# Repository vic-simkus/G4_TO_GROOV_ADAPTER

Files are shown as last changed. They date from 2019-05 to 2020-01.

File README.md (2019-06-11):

# G4 TO GROOV ADAPTER
## Motivation
I found out, after purchasing a pile of gear, that the G4 output modules mounted in a G4PB24 would not work with a GRV-ODCSRC-24.  Reason being that the GRV-ODCSRC-24 is a "sourcing" module, while the G4PB24 expects a "sinking" module.  

While this could have been better documented by OPTO 22, it is what is it and I needed to be able to used the G4PB24 for my project.  Nothing else would do for various reasons.

Hence this project.  The project is an adapter board with a 50 pin ribbon connector on one end and a spring loaded terminal on the other end.  The design is super simple - it's 24 NPN transistors.  

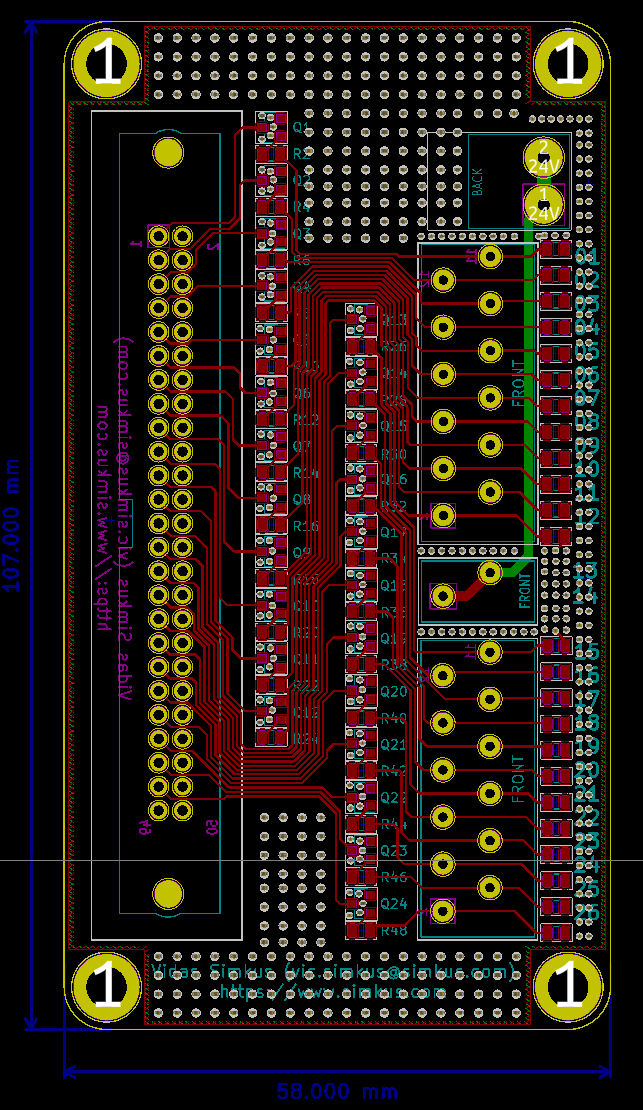
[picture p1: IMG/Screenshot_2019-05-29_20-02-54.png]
Board screen shot


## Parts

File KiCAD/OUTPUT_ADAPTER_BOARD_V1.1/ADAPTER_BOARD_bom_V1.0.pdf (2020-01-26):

ADAPTER_BOARD_bom_V1.0
Description | References | Value | Quantity
Connector, 02x25 | BOARD1 | | 1
Connector, 01x02 | PLC24 | | 1
Connector, 01x12 | PLC1-12 PLC13-14 | | 2
NPN transistor | Q1 Q2 Q3 Q4 Q5 Q6 Q7 Q8 Q9 Q10 Q11 Q12 Q13 Q14 Q15 Q16 Q17 Q18 Q19 Q20 Q21 Q22 Q23 Q24 | | 24
Resistor | R2 R4 R6 R8 R10 R12 R14 R16 R18 R20 R22 R24 R26 R28 R30 R32 R34 R36 R38 R40 R42 R44 R46 R48 | 10K | 24
Resistor | R1 R3 R5 R7 R9 R11 R13 R15 R17 R19 R21 R23 R25 R27 R29 R31 R33 R35 R37 R39 R41 R43 R45 R47 | 5K6 | 24
Connector, 01x02 | VDC24 | | 1

ADAPTER_BOARD_bom_V1.0
MFG | MFGPN | DKPN
AMPHENOL ICC (FCI) | 71918-150LF | 609-1759-ND
PHOENIX CONTACT | 1990009 | 277-1794-ND
PHOENIX CONTACT | 1990106 | 277-1804-ND
Diodes Incorporated | MMBTA42-7-F | MMBTA42-FDICT-ND
TE Connectivity Passive Product | CRGCQ0805F10K | A129761CT-ND
Panasonic Electronic Components | ERJ-P06J562V | P5.6KADCT-ND
PHOENIX CONTACT | 1990009 | 277-1794-ND

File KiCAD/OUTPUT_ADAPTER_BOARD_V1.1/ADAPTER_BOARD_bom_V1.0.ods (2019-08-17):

Description | References | Value | Quantity | MFG | MFGPN | DKPN
Connector, 02x25 | BOARD1 |  | 1 | AMPHENOL ICC (FCI) | 71918-150LF | 609-1759-ND
Connector, 01x02 | PLC24 |  | 1 | PHOENIX CONTACT | 1990009 | 277-1794-ND
Connector, 01x12 | PLC1-12 PLC13-14 |  | 2 | PHOENIX CONTACT | 1990106 | 277-1804-ND
NPN transistor | Q1 Q2 Q3 Q4 Q5 Q6 Q7 Q8 Q9 Q10 Q11 Q12 Q13 Q14 Q15 Q16 Q17 Q18 Q19 Q20 Q21 Q22 Q23 Q24 |  | 24 | Diodes Incorporated | MMBTA42-7-F | MMBTA42-FDICT-ND
Resistor | R2 R4 R6 R8 R10 R12 R14 R16 R18 R20 R22 R24 R26 R28 R30 R32 R34 R36 R38 R40 R42 R44 R46 R48 | 10K | 24 | TE Connectivity Passive Product | CRGCQ0805F10K | A129761CT-ND
Resistor | R1 R3 R5 R7 R9 R11 R13 R15 R17 R19 R21 R23 R25 R27 R29 R31 R33 R35 R37 R39 R41 R43 R45 R47 | 5K6 | 24 | Panasonic Electronic Components | ERJ-P06J562V | P5.6KADCT-ND
Connector, 01x02 | VDC24 |  | 1 | PHOENIX CONTACT | 1990009 | 277-1794-ND

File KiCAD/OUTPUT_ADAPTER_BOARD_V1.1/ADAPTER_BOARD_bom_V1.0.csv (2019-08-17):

Component | Description | Part | References | Value | Footprint | Quantity Per PCB | Datasheet | MFG | MFGPN | DKPN | TCR | TOL | PD
1 | Generic connector, double row, 02x25, odd/even pin numbering scheme (row 1 odd numbers, row 2 even numbers), script generated (kicad-library-utils/schlib/autogen/connector/) | Conn_02x25_Odd_Even | BOARD1 | Conn_02x25_Odd_Even | FCI_50PIN | 1 | ~ | AMPHENOL ICC (FCI) | 71918-150LF | 609-1759-ND
2 | Generic connector, single row, 01x02, script generated (kicad-library-utils/schlib/autogen/connector/) | Conn_01x02 | PLC24 | Conn_01x02 | 2_POS_SPRING_TERM | 1 | ~ | PHOENIX CONTACT | 1990009 | 277-1794-ND
3 | Generic connector, single row, 01x12, script generated (kicad-library-utils/schlib/autogen/connector/) | Conn_01x12 | PLC1-12 PLC13-14 | Conn_01x12 | 12_POS_SPRING_TERM | 2 | ~ | PHOENIX CONTACT | 1990106 | 277-1804-ND
4 | NPN transistor, base/emitter/collector | Q_NPN_BEC | Q1 Q2 Q3 Q4 Q5 Q6 Q7 Q8 Q9 Q10 Q11 Q12 Q13 Q14 Q15 Q16 Q17 Q18 Q19 Q20 Q21 Q22 Q23 Q24 | Q_NPN_CBE | SOT-23 | 24 | ~ | Diodes Incorporated | MMBTA42-7-F | MMBTA42-FDICT-ND
5 | Resistor | R | R2 R4 R6 R8 R10 R12 R14 R16 R18 R20 R22 R24 R26 R28 R30 R32 R34 R36 R38 R40 R42 R44 R46 R48 | 10K | R_0805_2012Metric | 24 | ~ | TE Connectivity Passive Product | CRGCQ0805F10K | A129761CT-ND | 100 | 1%
6 | Resistor | R | R1 R3 R5 R7 R9 R11 R13 R15 R17 R19 R21 R23 R25 R27 R29 R31 R33 R35 R37 R39 R41 R43 R45 R47 | 5K6 | R_0805_2012Metric | 24 | ~ | Panasonic Electronic Components | ERJ-P06J562V | P5.6KADCT-ND | 200 | 5% | 0.5W
7 | Generic connector, single row, 01x02, script generated (kicad-library-utils/schlib/autogen/connector/) | Conn_01x02 | VDC24 | Conn_01x02 | 2_POS_SCREW_TERM | 1 | ~ | PHOENIX CONTACT | 1990009 | 277-1794-ND
Component Groups: | 7
Component Count: | 77
Fitted Components: | 77
Number of PCBs: | 1
Total components: | 77
Schematic Version: | V1.0
Schematic Date: | 2019-05-24
BoM Date: | Fri 16 Aug 2019 07:38:34 PM CDT
Schematic Source: | /opt/dev/git_work/G4_TO_GROOV_ADAPTER/KiCAD/OUTPUT_ADAPTER_BOARD_V1.1/ADAPTER_BOARD.sch
KiCad Version: | Eeschema 5.0.2-bee76a0~70~ubuntu18.04.1

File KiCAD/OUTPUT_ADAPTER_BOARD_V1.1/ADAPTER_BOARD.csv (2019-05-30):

Id | Designator | Package | Quantity | Designation | Supplier and ref
1 | BOARD1 | FCI_50PIN | 1 | Conn_02x25_Odd_Even
2 | PLC1-12,PLC13-14 | 12_POS_SPRING_TERM | 2 | Conn_01x12
3 | PLC24 | 2_POS_SPRING_TERM | 1 | Conn_01x02
4 | R18,R2,R4,R6,R8,R10,R12,R14,R16,R20,R22,R24,R26,R28,R30,R32,R34,R36,R38,R40,R42,R44,R46,R48 | R_0805_2012Metric | 24 | 2K2
5 | Q5,Q1,Q2,Q3,Q4,Q6,Q7,Q8,Q9,Q10,Q11,Q12,Q13,Q14,Q15,Q16,Q17,Q18,Q19,Q20,Q21,Q22,Q23,Q24 | SOT-23 | 24 | Q_NPN_CBE
6 | VDC24 | 2_POS_SCREW_TERM | 1 | Conn_01x02
7 | REF**,REF**,REF**,REF** | MountingHole_4.3mm_M4_ISO14580_Pad | 4 | MountingHole_4.3mm_M4_ISO14580_Pad
8 | R1,R3,R5,R7,R9,R11,R13,R15,R17,R19,R21,R23,R25,R27,R29,R31,R33,R35,R37,R39,R41,R43,R45,R47 | R_0805_2012Metric | 24 | 10K

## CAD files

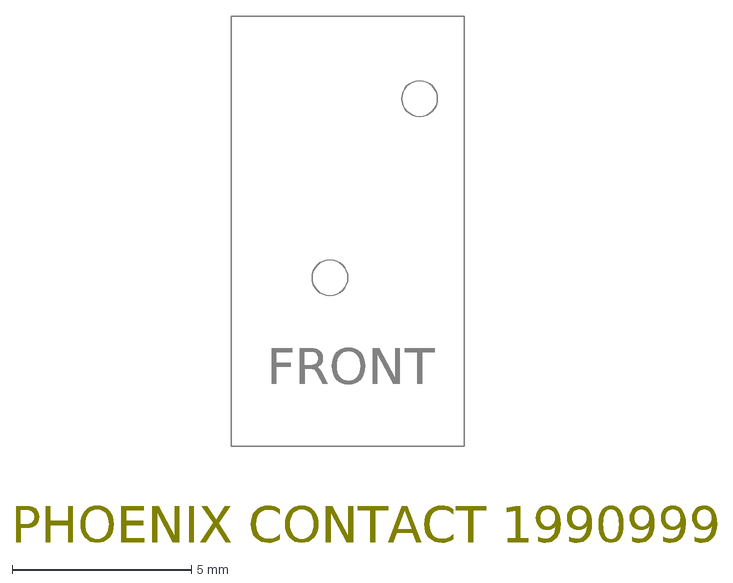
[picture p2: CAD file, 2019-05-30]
CAD/2POS_PCB_TERM_SPRING.dxf
FRONT
PHOENIX CONTACT 1990999

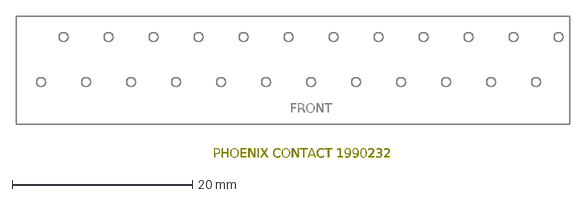
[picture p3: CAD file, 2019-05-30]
CAD/24POS_PCB_TERM.dxf
FRONT
PHOENIX CONTACT 1990232

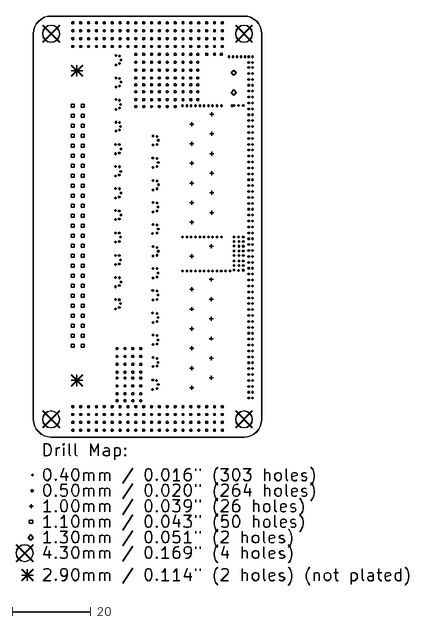
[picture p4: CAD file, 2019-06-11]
KiCAD/OUTPUT_ADAPTER_BOARD_V1.1/DXF/ADAPTER_BOARD-drl_map.dxf
99.7 x 144.6

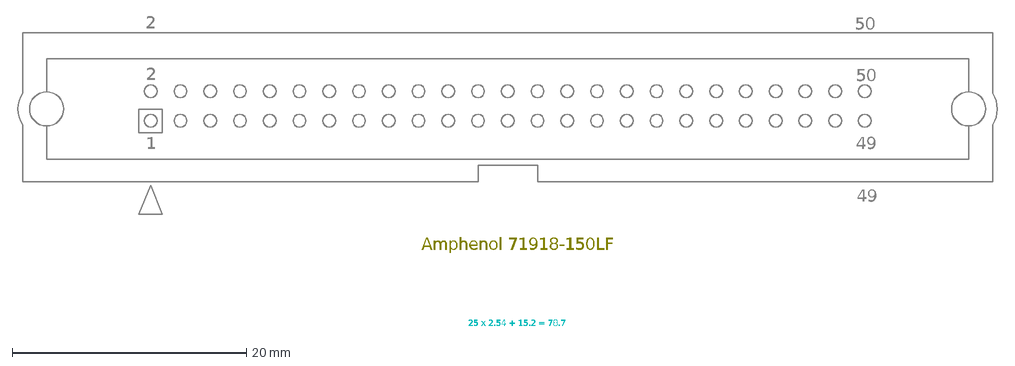
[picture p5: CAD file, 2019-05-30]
CAD/CONN-50PIN.dxf
1
49
50
2
25 x 2.54 + 15.2 = 78.7
Amphenol 71918-150LF

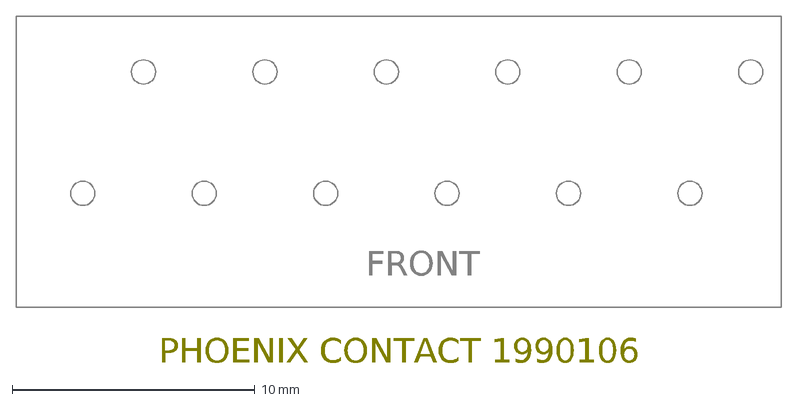
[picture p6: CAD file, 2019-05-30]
CAD/12POS_PCB_TERM_SPRING.dxf
FRONT
PHOENIX CONTACT 1990106

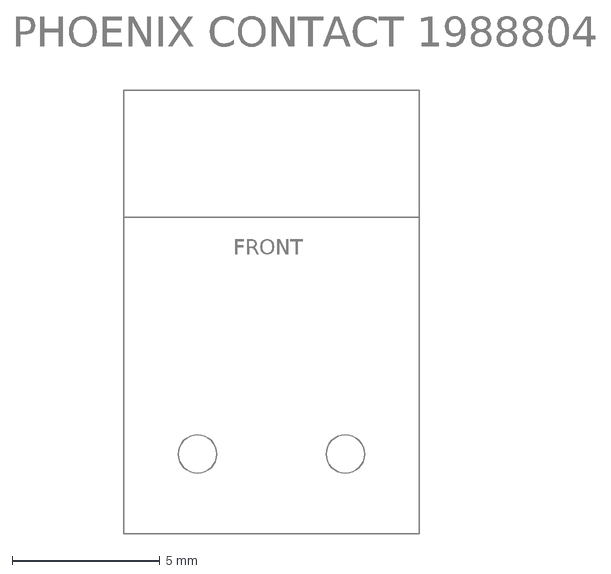
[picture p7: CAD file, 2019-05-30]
CAD/2POS_PCB_TERM.dxf
PHOENIX CONTACT 1988804
FRONT

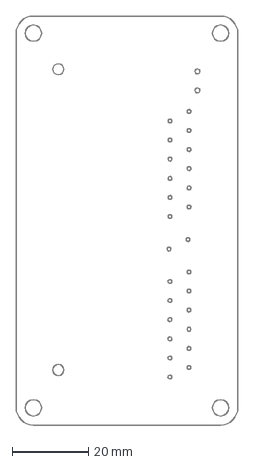
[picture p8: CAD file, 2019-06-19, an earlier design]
KiCAD/OUTPUT_ADAPTER_BOARD/DXF/ADAPTER_BOARD-layout.dxf
58.0 x 107.0 mm

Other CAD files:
KiCAD/OUTPUT_ADAPTER_BOARD_V1.1/DXF/ADAPTER_BOARD.dxf

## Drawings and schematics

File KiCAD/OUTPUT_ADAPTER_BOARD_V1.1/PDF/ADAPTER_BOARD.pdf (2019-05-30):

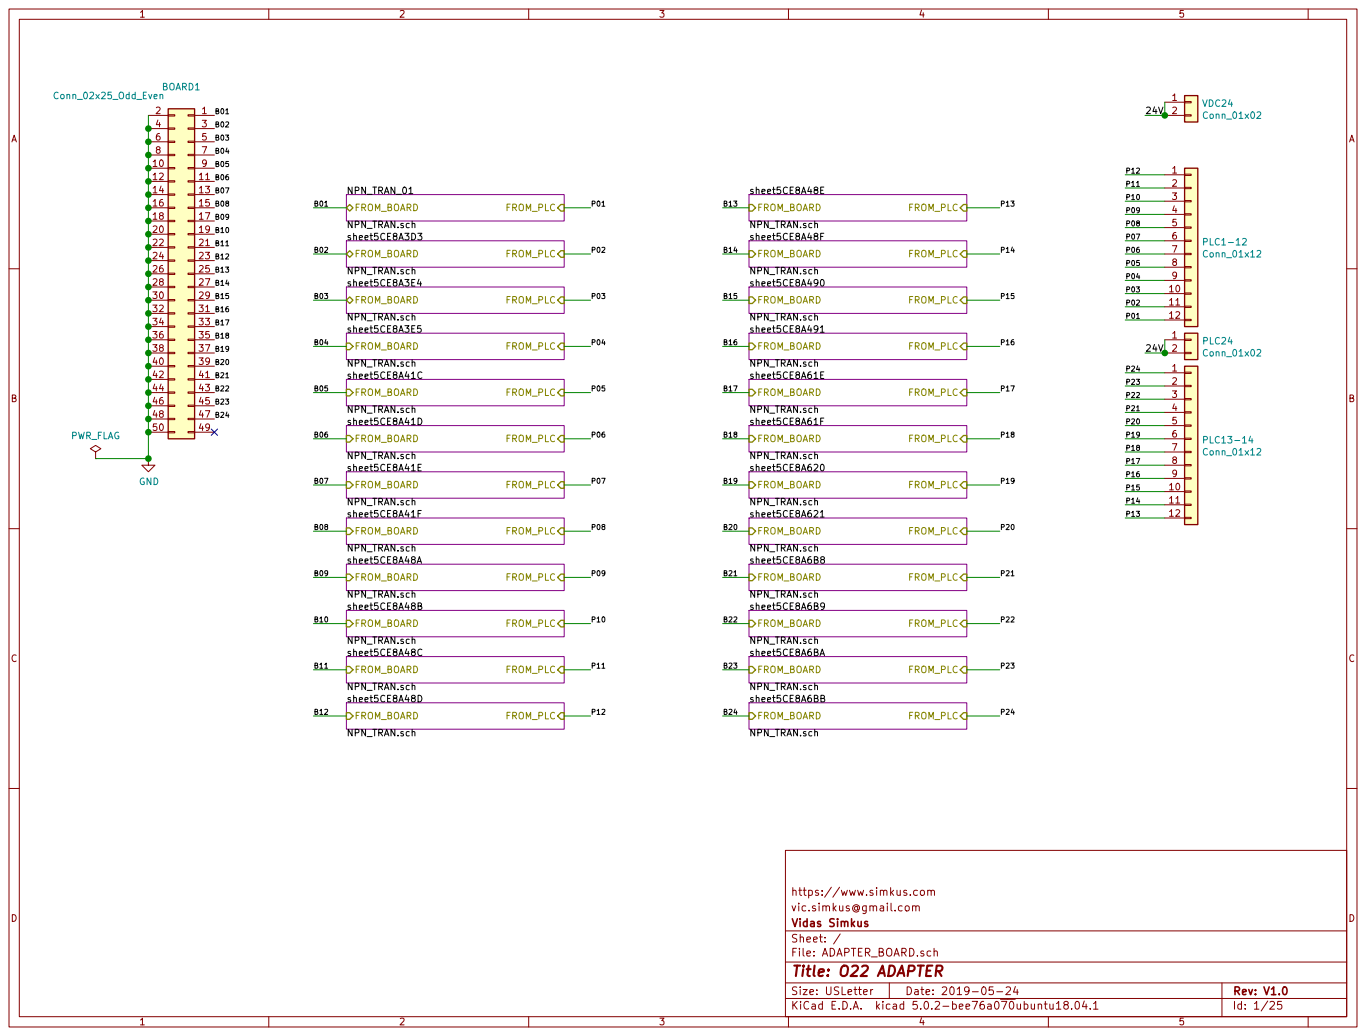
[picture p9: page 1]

vic.simkus@gmail.com
File: ADAPTER_BOARD.sch Sheet: / Vidas Simkus

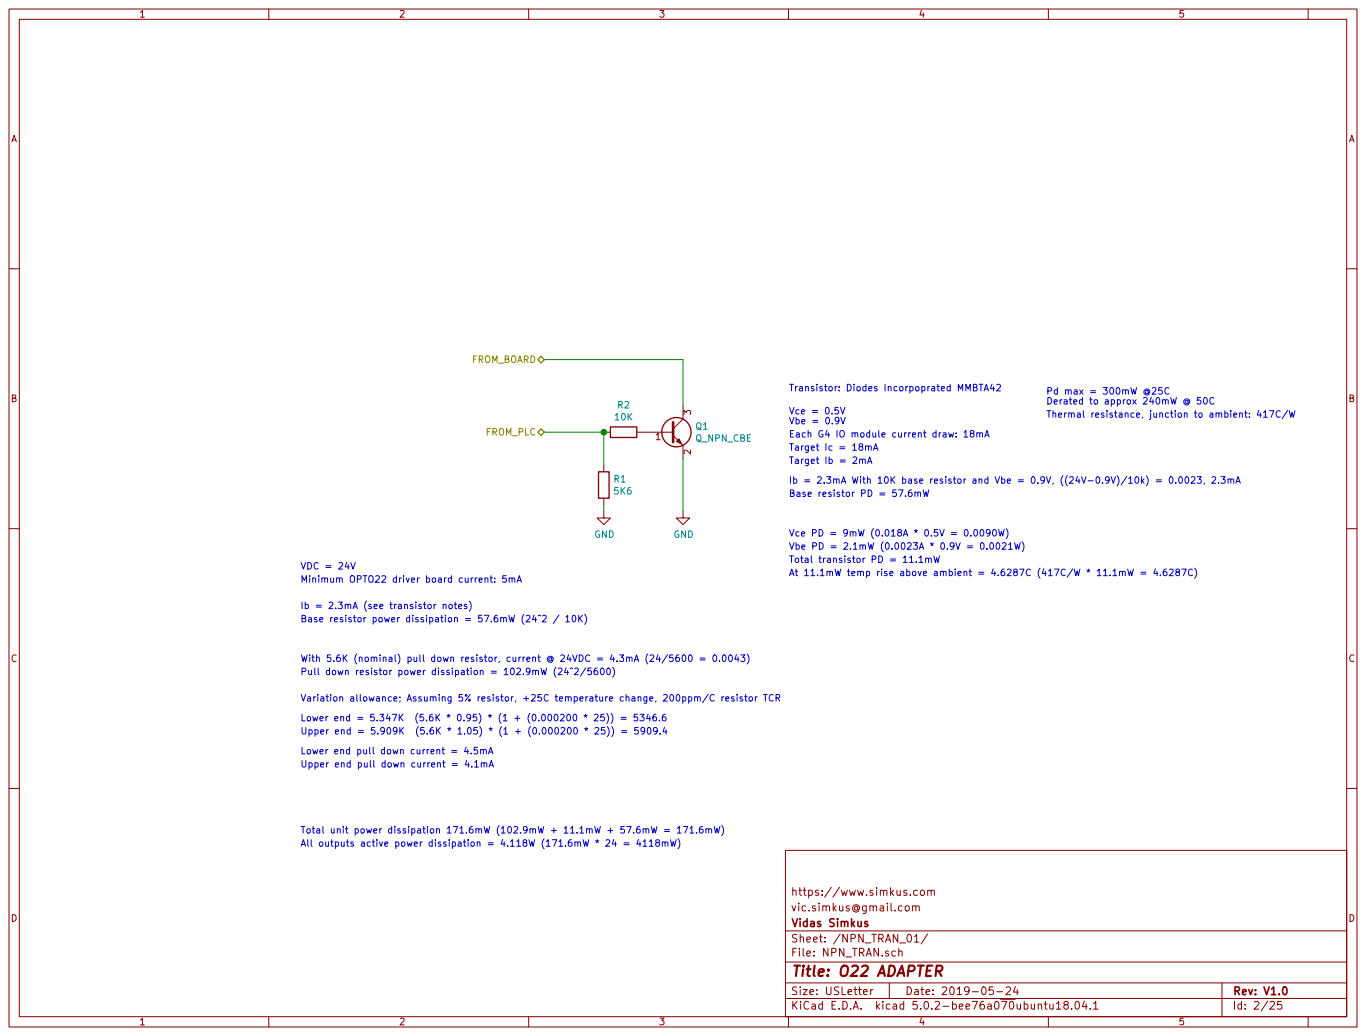
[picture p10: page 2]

Transistor: Diodes Incorpoprated MMBTA42 Vce = 0.5V

Pd max = 300mW @25C
Derated to approx 240mW @ 50C
Thermal resistance, junction to ambient: 417C/W

Vbe = 0.9V
Each G4 IO module current draw: 18mA
Target Ic = 18mA
Target Ib = 2mA
Ib = 2.3mA With 10K base resistor and Vbe = 0.9V, ((24V-0.9V)/10k) = 0.0023, 2.3mA
Base resistor PD = 57.6mW

Vce PD = 9mW (0.018A * 0.5V = 0.0090W)
Vbe PD = 2.1mW (0.0023A * 0.9V = 0.0021W) Total transistor PD = 11.1mW

VDC = 24V
Ib = 2.3mA (see transistor notes) Minimum OPTO22 driver board current: 5mA

At 11.1mW temp rise above ambient = 4.6287C (417C/W * 11.1mW = 4.6287C)

Base resistor power dissipation = 57.6mW (24^2 / 10K)

With 5.6K (nominal) pull down resistor, current @ 24VDC = 4.3mA (24/5600 = 0.0043)
Pull down resistor power dissipation = 102.9mW (24^2/5600)

Variation allowance; Assuming 5% resistor, +25C temperature change, 200ppm/C resistor TCR
Lower end = 5.347K (5.6K * 0.95) * (1 + (0.000200 * 25)) = 5346.6
Upper end = 5.909K (5.6K * 1.05) * (1 + (0.000200 * 25)) = 5909.4
Lower end pull down current = 4.5mA
Upper end pull down current = 4.1mA

Total unit power dissipation 171.6mW (102.9mW + 11.1mW + 57.6mW = 171.6mW)
All outputs active power dissipation = 4.118W (171.6mW * 24 = 4118mW)

https://www.simkus.com
vic.simkus@gmail.com
Sheet: /NPN_TRAN_01/ Vidas Simkus

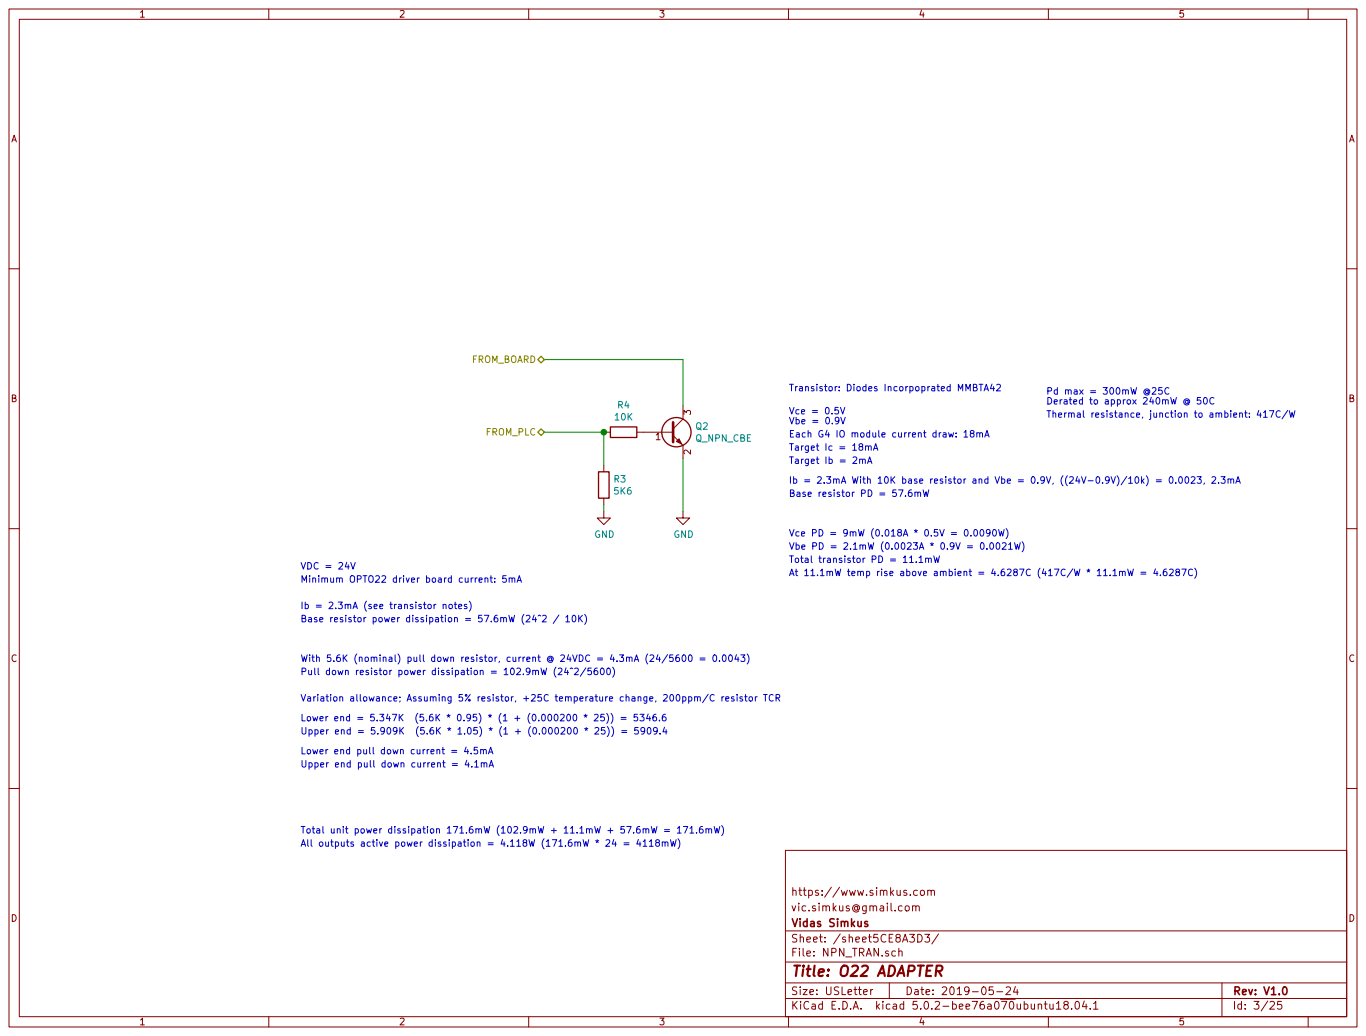
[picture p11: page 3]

Transistor: Diodes Incorpoprated MMBTA42 Vce = 0.5V

Pd max = 300mW @25C
Derated to approx 240mW @ 50C
Thermal resistance, junction to ambient: 417C/W

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

VDC = 24V
Ib = 2.3mA (see transistor notes) Minimum OPTO22 driver board current: 5mA

At 11.1mW temp rise above ambient = 4.6287C (417C/W * 11.1mW = 4.6287C)

Base resistor power dissipation = 57.6mW (24^2 / 10K)

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

https://www.simkus.com
vic.simkus@gmail.com
File: NPN_TRAN.sch Sheet: /sheet5CE8A3D3/ Vidas Simkus

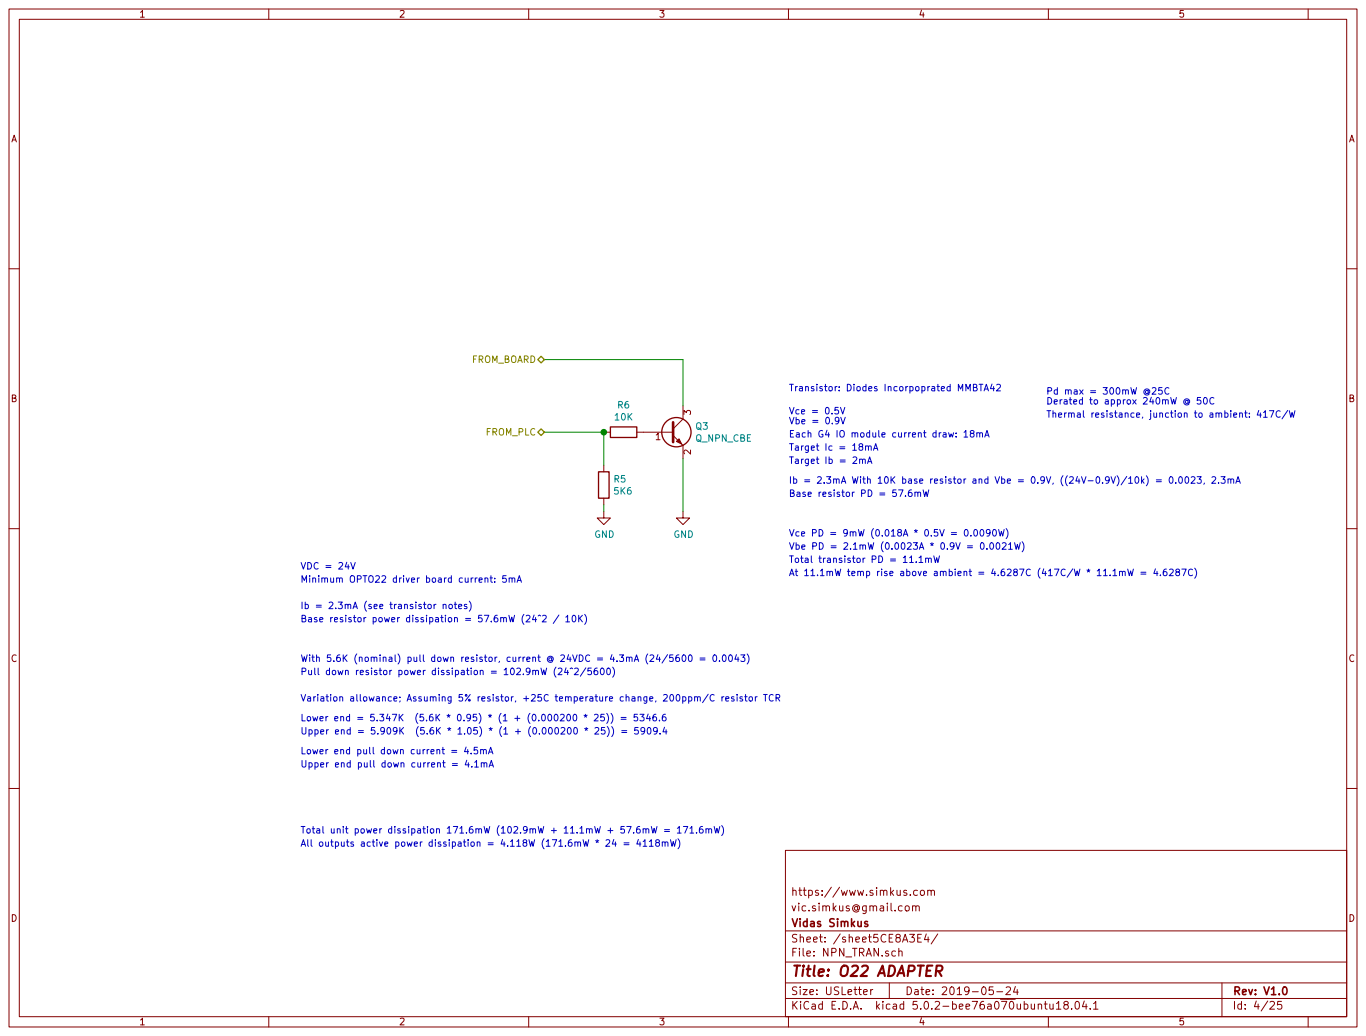
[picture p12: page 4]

Transistor: Diodes Incorpoprated MMBTA42 Vce = 0.5V

Pd max = 300mW @25C
Derated to approx 240mW @ 50C
Thermal resistance, junction to ambient: 417C/W

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

VDC = 24V
Ib = 2.3mA (see transistor notes) Minimum OPTO22 driver board current: 5mA

At 11.1mW temp rise above ambient = 4.6287C (417C/W * 11.1mW = 4.6287C)

Base resistor power dissipation = 57.6mW (24^2 / 10K)

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

https://www.simkus.com
vic.simkus@gmail.com
File: NPN_TRAN.sch Sheet: /sheet5CE8A3E4/ Vidas Simkus

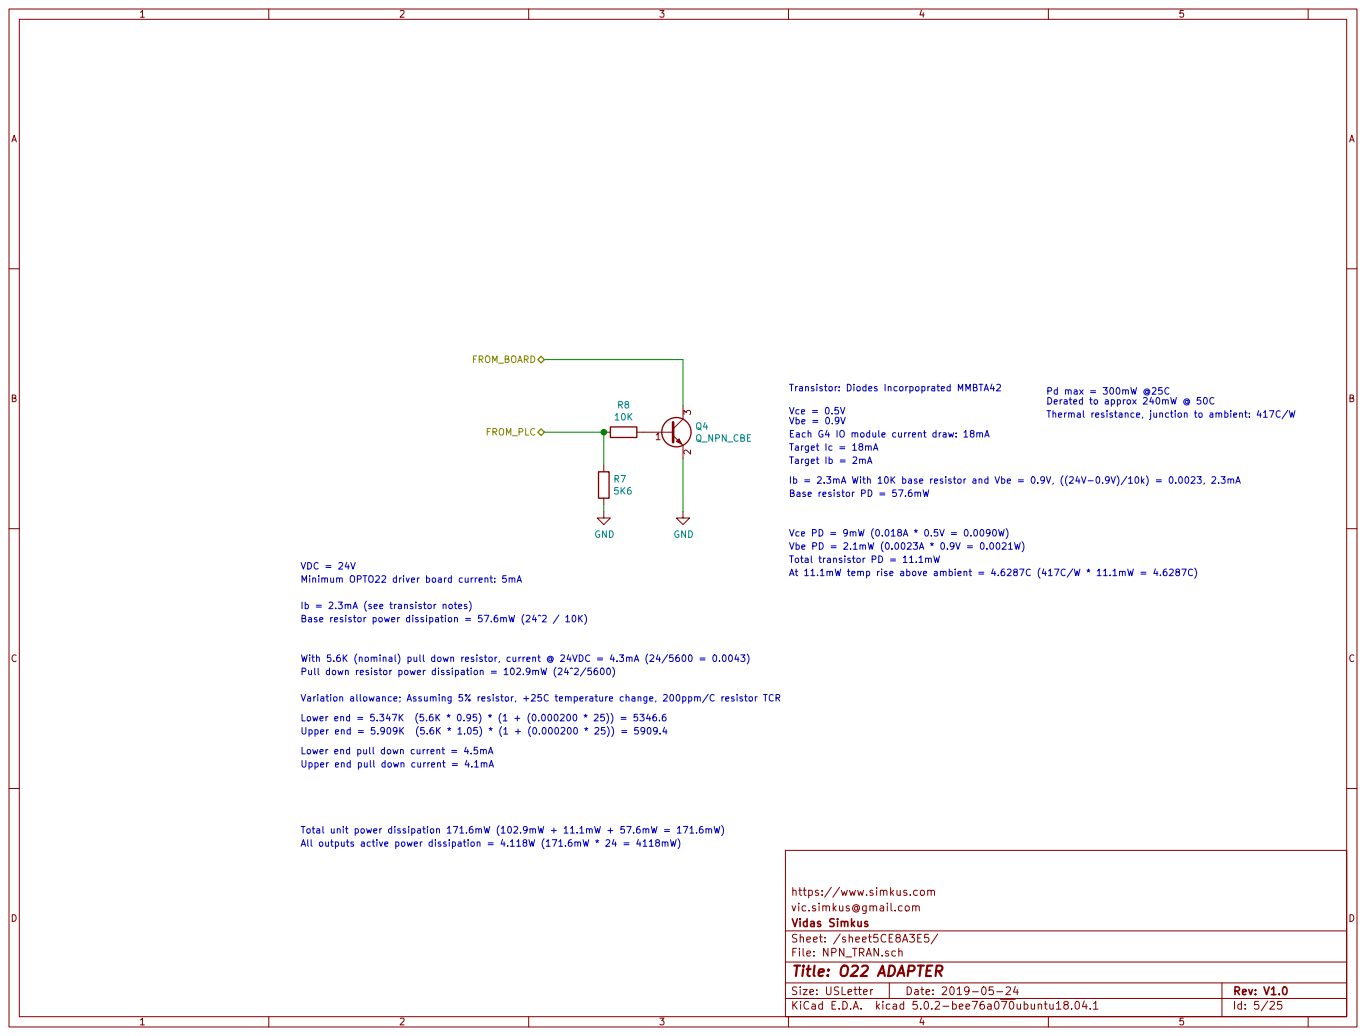
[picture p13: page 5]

Transistor: Diodes Incorpoprated MMBTA42 Vce = 0.5V

Pd max = 300mW @25C
Derated to approx 240mW @ 50C
Thermal resistance, junction to ambient: 417C/W
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

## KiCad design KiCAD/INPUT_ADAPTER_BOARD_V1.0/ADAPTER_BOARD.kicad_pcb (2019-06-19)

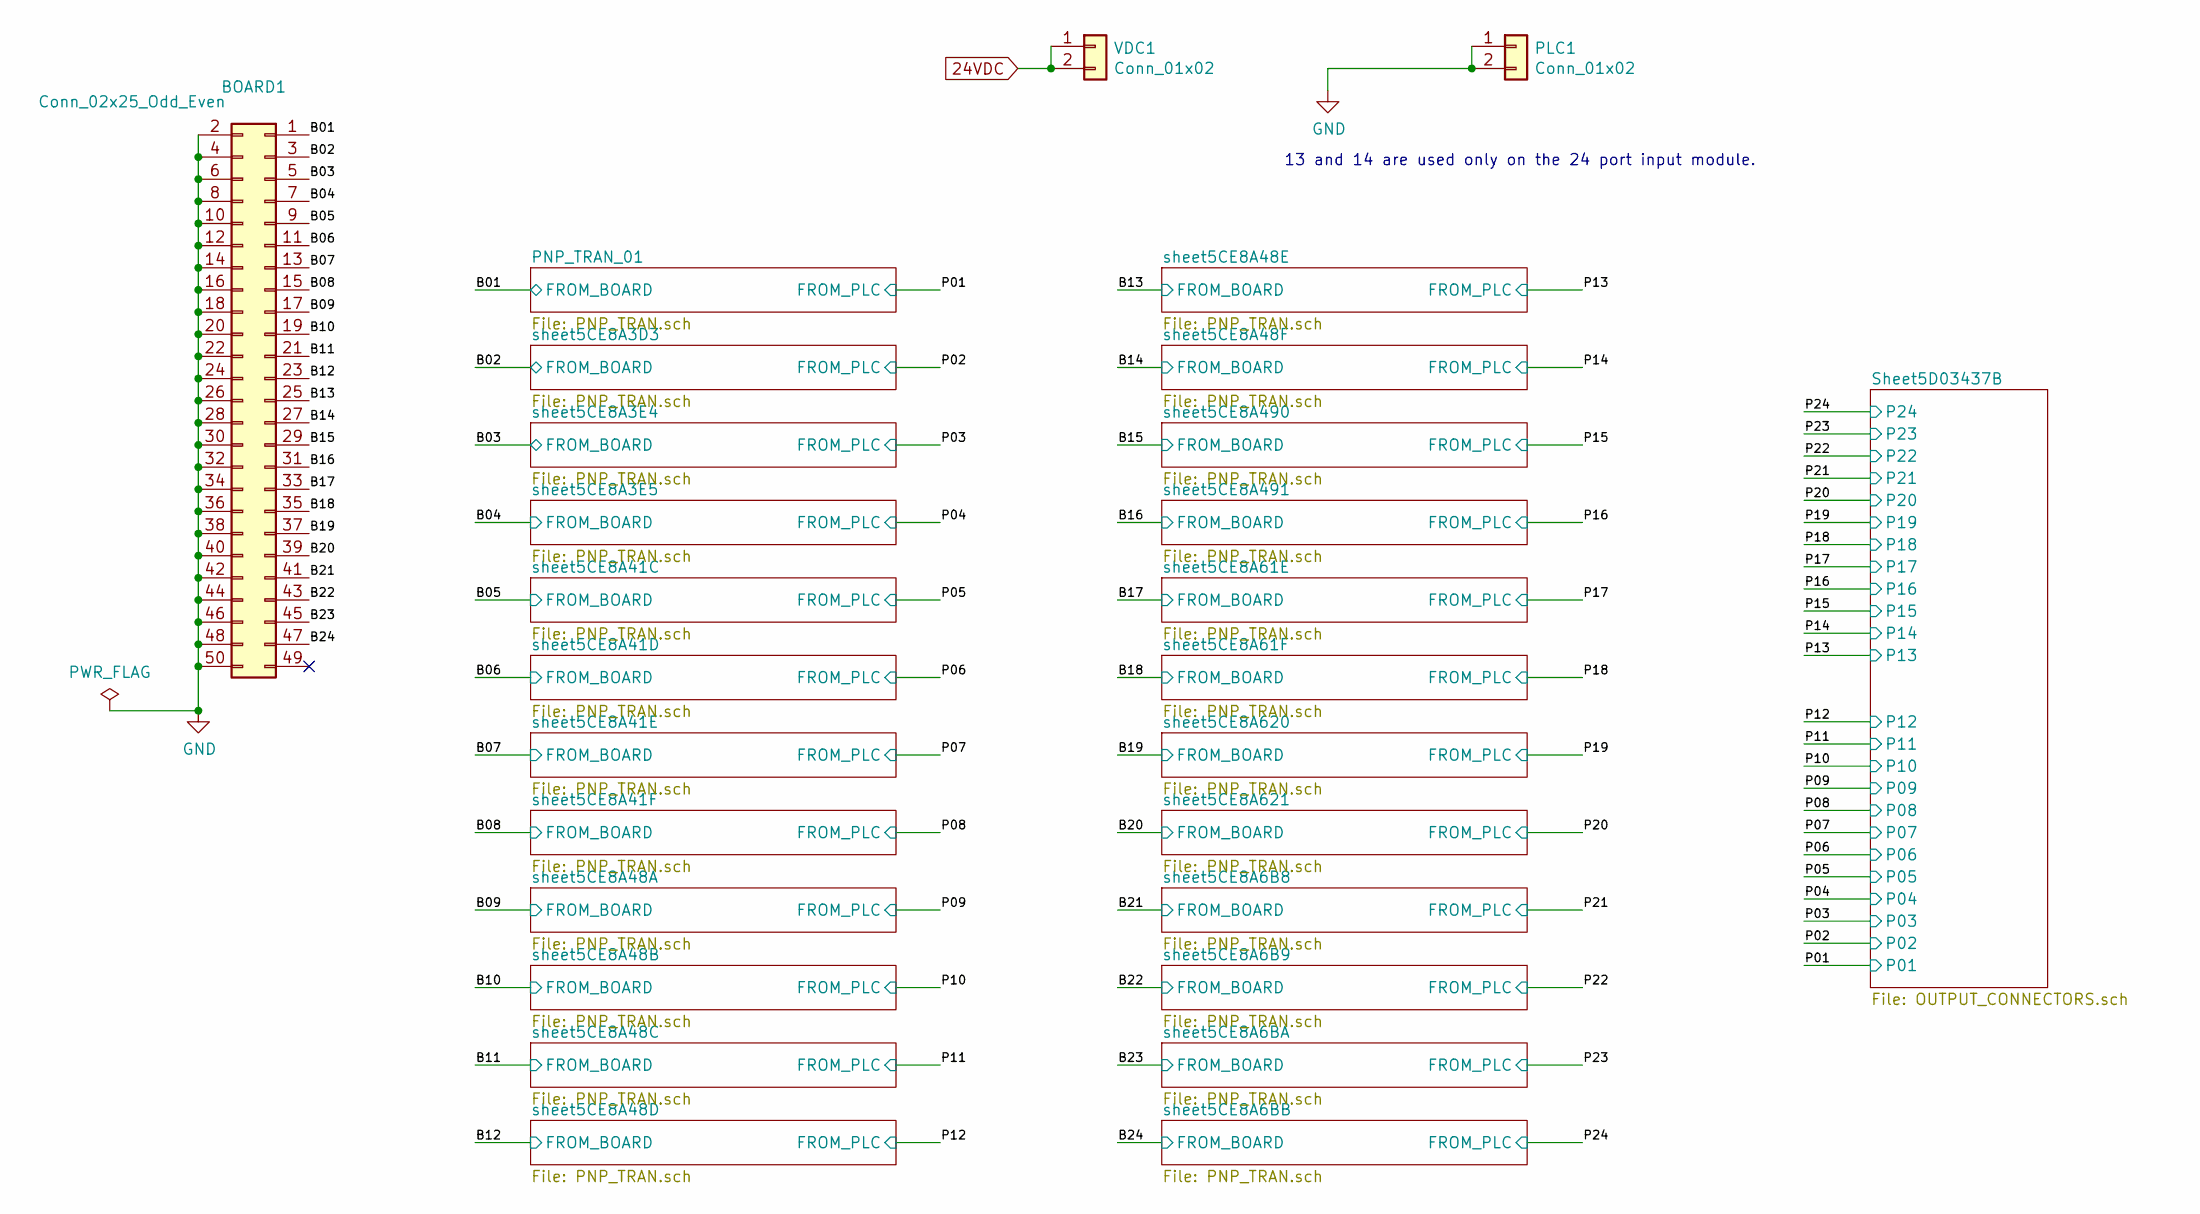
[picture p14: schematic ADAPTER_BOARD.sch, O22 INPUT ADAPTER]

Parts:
BOARD1: Conn_02x25_Odd_Even; FCI_50PIN; MFGPN 71918-150LF
PLC1: Conn_01x02; 2_POS_SPRING_TERM; MFGPN 1990009
VDC1: Conn_01x02; 2_POS_SCREW_TERM; MFGPN 1990009

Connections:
24VDC: VDC1.1, VDC1.2; also elsewhere on the board
/B01: BOARD1.1; also elsewhere on the board
/B02: BOARD1.3; also elsewhere on the board
/B03: BOARD1.5; also elsewhere on the board
/B04: BOARD1.7; also elsewhere on the board
/B05: BOARD1.9; also elsewhere on the board
/B06: BOARD1.11; also elsewhere on the board
/B07: BOARD1.13; also elsewhere on the board
/B08: BOARD1.15; also elsewhere on the board
/B09: BOARD1.17; also elsewhere on the board
/B10: BOARD1.19; also elsewhere on the board
/B11: BOARD1.21; also elsewhere on the board
/B12: BOARD1.23; also elsewhere on the board
/B13: BOARD1.25; also elsewhere on the board
/B14: BOARD1.27; also elsewhere on the board
/B15: BOARD1.29; also elsewhere on the board
/B16: BOARD1.31; also elsewhere on the board
/B17: BOARD1.33; also elsewhere on the board
/B18: BOARD1.35; also elsewhere on the board
/B19: BOARD1.37; also elsewhere on the board
/B20: BOARD1.39; also elsewhere on the board
/B21: BOARD1.41; also elsewhere on the board
/B22: BOARD1.43; also elsewhere on the board
/B23: BOARD1.45; also elsewhere on the board
/B24: BOARD1.47; also elsewhere on the board
GND: BOARD1.2, BOARD1.4, BOARD1.6, BOARD1.8, BOARD1.10, BOARD1.12, BOARD1.14, BOARD1.16, BOARD1.18, BOARD1.20, BOARD1.22, BOARD1.24, BOARD1.26, BOARD1.28, BOARD1.30, BOARD1.32, BOARD1.34, BOARD1.36, BOARD1.38, BOARD1.40, BOARD1.42, BOARD1.44, BOARD1.46, BOARD1.48, BOARD1.50, PLC1.1, PLC1.2; also elsewhere on the board

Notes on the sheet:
13 and 14 are used only on the 24 port input module.

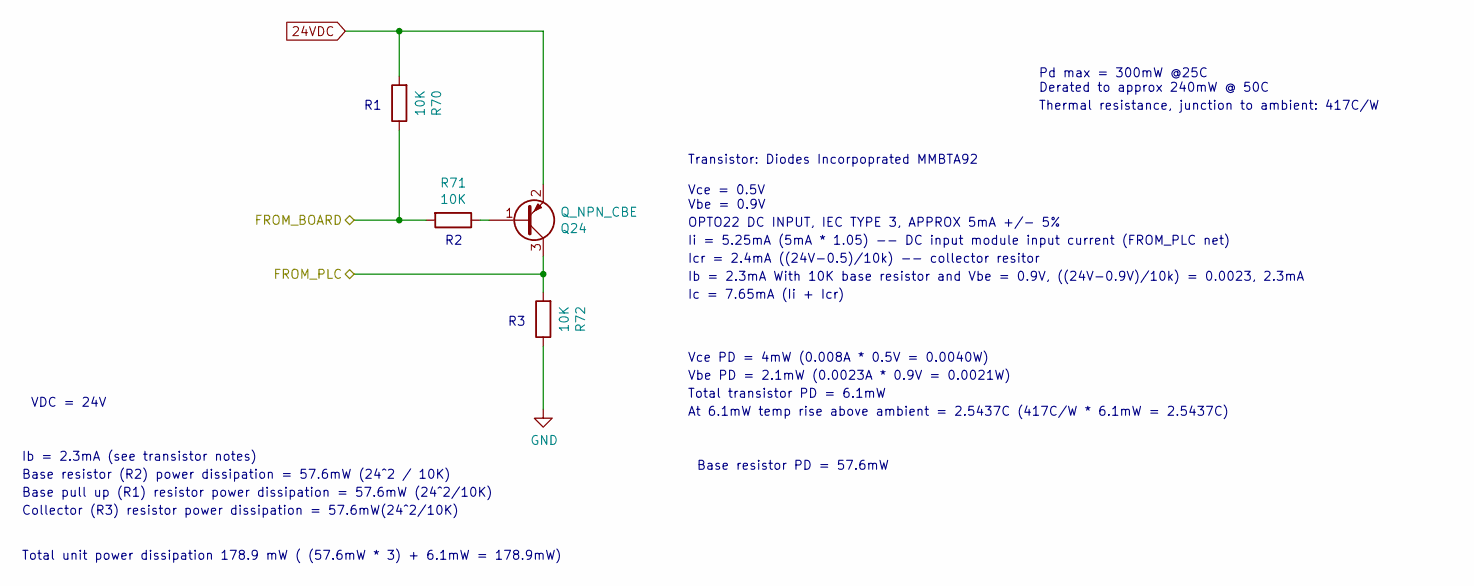
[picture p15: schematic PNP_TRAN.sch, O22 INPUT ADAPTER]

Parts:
Q1: Q_NPN_CBE; SOT-23; MFGPN MMBTA42-7-F
R1, R2, R3: 10K; R_0805_2012Metric; MFGPN CRGCQ0805F10K

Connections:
24VDC: Q1.2 (E), R1.2; also elsewhere on the board
/B01: R1.1, R2.2; also elsewhere on the board
/P01: Q1.3 (C), R3.2; also elsewhere on the board
GND: R3.1; also elsewhere on the board
unnamed: Q1.1 (B), R2.1

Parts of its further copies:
Q2, Q3, Q4, Q5, Q6, Q7, Q8, Q9, Q10, Q11, Q12, Q13, Q14, Q15, Q16, Q17, Q18, Q19, Q20, Q21, Q22, Q23, Q24: Q_NPN_CBE; SOT-23; MFGPN MMBTA42-7-F
R4, R5, R6, R7, R8, R9, R10, R11, R12, R13, R14, R15, R16, R17, R18, R19, R20, R21, R22, R23, R24, R25, R26, R27, R28, R29, R30, R31, R32, R33, R34, R35, R36, R37, R38, R39, R40, R41, R42, R43, R44, R45, R46, R47, R48, R49, R50, R51, R52, R53, R54, R55, R56, R57, R58, R59, R60, R61, R62, R63, R64, R65, R66, R67, R68, R69, R70, R71, R72: 10K; R_0805_2012Metric; MFGPN CRGCQ0805F10K

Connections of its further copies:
24VDC: Q2.2 (E), Q3.2 (E), Q4.2 (E), Q5.2 (E), Q6.2 (E), Q7.2 (E), Q8.2 (E), Q9.2 (E), Q10.2 (E), Q11.2 (E), Q12.2 (E), Q13.2 (E), Q14.2 (E), Q15.2 (E), Q16.2 (E), Q17.2 (E), Q18.2 (E), Q19.2 (E), Q20.2 (E), Q21.2 (E), Q22.2 (E), Q23.2 (E), Q24.2 (E), R4.2, R7.2, R10.2, R13.2, R16.2, R19.2, R22.2, R25.2, R28.2, R31.2, R34.2, R37.2, R40.2, R43.2, R46.2, R49.2, R52.2, R55.2, R58.2, R61.2, R64.2, R67.2, R70.2; also elsewhere on the board
/B02: R4.1, R5.2; also elsewhere on the board
/B03: R7.1, R8.2; also elsewhere on the board
/B04: R10.1, R11.2; also elsewhere on the board
/B05: R13.1, R14.2; also elsewhere on the board
/B06: R16.1, R17.2; also elsewhere on the board
/B07: R19.1, R20.2; also elsewhere on the board
/B08: R22.1, R23.2; also elsewhere on the board
/B09: R25.1, R26.2; also elsewhere on the board
/B10: R28.1, R29.2; also elsewhere on the board
/B11: R31.1, R32.2; also elsewhere on the board
/B12: R34.1, R35.2; also elsewhere on the board
/B13: R37.1, R38.2; also elsewhere on the board
/B14: R40.1, R41.2; also elsewhere on the board
/B15: R43.1, R44.2; also elsewhere on the board
/B16: R46.1, R47.2; also elsewhere on the board
/B17: R49.1, R50.2; also elsewhere on the board
/B18: R52.1, R53.2; also elsewhere on the board
/B19: R55.1, R56.2; also elsewhere on the board
/B20: R58.1, R59.2; also elsewhere on the board
/B21: R61.1, R62.2; also elsewhere on the board
/B22: R64.1, R65.2; also elsewhere on the board
/B23: R67.1, R68.2; also elsewhere on the board
/B24: R70.1, R71.2; also elsewhere on the board
/P02: Q2.3 (C), R6.2; also elsewhere on the board
/P03: Q3.3 (C), R9.2; also elsewhere on the board
/P04: Q4.3 (C), R12.2; also elsewhere on the board
/P05: Q5.3 (C), R15.2; also elsewhere on the board
/P06: Q6.3 (C), R18.2; also elsewhere on the board
/P07: Q7.3 (C), R21.2; also elsewhere on the board
/P08: Q8.3 (C), R24.2; also elsewhere on the board
/P09: Q9.3 (C), R27.2; also elsewhere on the board
/P10: Q10.3 (C), R30.2; also elsewhere on the board
/P11: Q11.3 (C), R33.2; also elsewhere on the board
/P12: Q12.3 (C), R36.2; also elsewhere on the board
/P13: Q13.3 (C), R39.2; also elsewhere on the board
/P14: Q14.3 (C), R42.2; also elsewhere on the board
/P15: Q15.3 (C), R45.2; also elsewhere on the board
/P16: Q16.3 (C), R48.2; also elsewhere on the board
/P17: Q17.3 (C), R51.2; also elsewhere on the board
/P18: Q18.3 (C), R54.2; also elsewhere on the board
/P19: Q19.3 (C), R57.2; also elsewhere on the board
/P20: Q20.3 (C), R60.2; also elsewhere on the board
/P21: Q21.3 (C), R63.2; also elsewhere on the board
/P22: Q22.3 (C), R66.2; also elsewhere on the board
/P23: Q23.3 (C), R69.2; also elsewhere on the board
/P24: Q24.3 (C), R72.2; also elsewhere on the board
GND: R6.1, R9.1, R12.1, R15.1, R18.1, R21.1, R24.1, R27.1, R30.1, R33.1, R36.1, R39.1, R42.1, R45.1, R48.1, R51.1, R54.1, R57.1, R60.1, R63.1, R66.1, R69.1, R72.1; also elsewhere on the board
unnamed: Q2.1 (B), R5.1
unnamed: Q3.1 (B), R8.1
unnamed: Q4.1 (B), R11.1
unnamed: Q5.1 (B), R14.1
unnamed: Q6.1 (B), R17.1
unnamed: Q7.1 (B), R20.1
unnamed: Q8.1 (B), R23.1
unnamed: Q9.1 (B), R26.1
unnamed: Q10.1 (B), R29.1
unnamed: Q11.1 (B), R32.1
unnamed: Q12.1 (B), R35.1
unnamed: Q13.1 (B), R38.1
unnamed: Q14.1 (B), R41.1
unnamed: Q15.1 (B), R44.1
unnamed: Q16.1 (B), R47.1
unnamed: Q17.1 (B), R50.1
unnamed: Q18.1 (B), R53.1
unnamed: Q19.1 (B), R56.1
unnamed: Q20.1 (B), R59.1
unnamed: Q21.1 (B), R62.1
unnamed: Q22.1 (B), R65.1
unnamed: Q23.1 (B), R68.1
unnamed: Q24.1 (B), R71.1

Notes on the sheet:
Transistor: Diodes Incorpoprated MMBTA92
Vce = 0.5V Vbe = 0.9V
Vce PD = 4mW (0.008A * 0.5V = 0.0040W)
Vbe PD = 2.1mW (0.0023A * 0.9V = 0.0021W)
Total transistor PD = 6.1mW
OPTO22 DC INPUT, IEC TYPE 3, APPROX 5mA +/- 5%
Ib = 2.3mA With 10K base resistor and Vbe = 0.9V, ((24V-0.9V)/10k) = 0.0023, 2.3mA
Pd max = 300mW @25C Derated to approx 240mW @ 50C
Thermal resistance, junction to ambient: 417C/W
At 6.1mW temp rise above ambient = 2.5437C (417C/W * 6.1mW = 2.5437C)
Base resistor PD = 57.6mW
Ii = 5.25mA (5mA * 1.05) -- DC input module input current (FROM_PLC net)
Icr = 2.4mA ((24V-0.5)/10k) -- collector resitor
Ic = 7.65mA (Ii + Icr)
Base resistor (R2) power dissipation = 57.6mW (24^2 / 10K)
Ib = 2.3mA (see transistor notes)
VDC = 24V
Total unit power dissipation 178.9 mW ( (57.6mW * 3) + 6.1mW = 178.9mW)
Base pull up (R1) resistor power dissipation = 57.6mW (24^2/10K)
Collector (R3) resistor power dissipation = 57.6mW(24^2/10K)

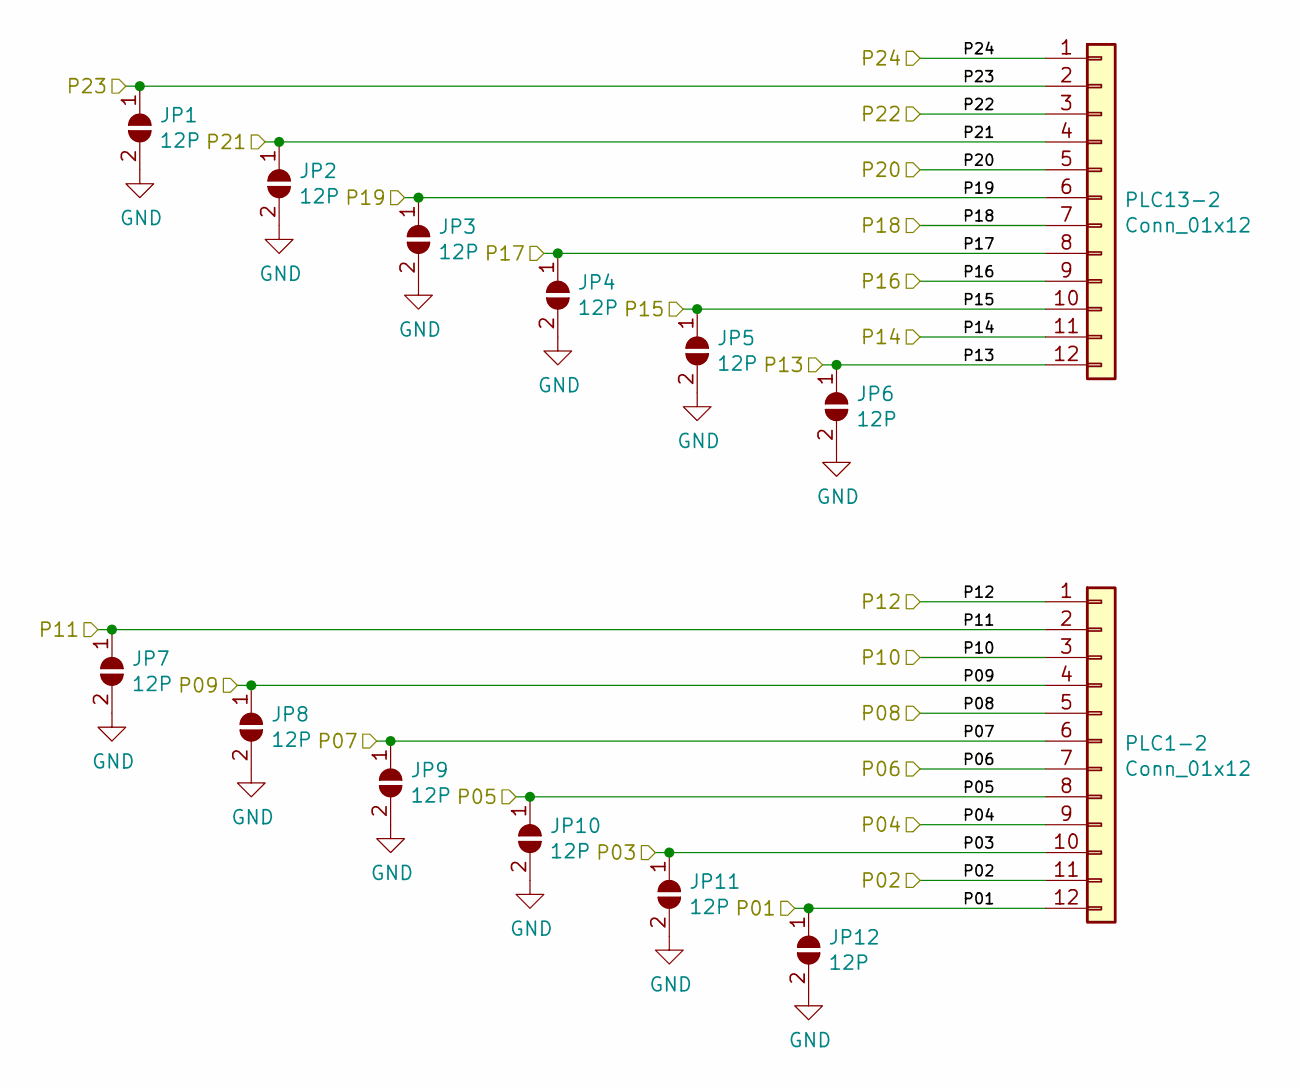
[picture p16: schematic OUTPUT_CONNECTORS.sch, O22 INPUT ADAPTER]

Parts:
JP1, JP2, JP3, JP4, JP5, JP6, JP7, JP8, JP9, JP10, JP11, JP12: 12P; SolderJumper-2_P1.3mm_Open_RoundedPad1.0x1.5mm
PLC1-2, PLC13-2: Conn_01x12; 12_POS_SPRING_TERM; MFGPN 1990106

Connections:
/P01: JP12.1 (A), PLC1-2.12; also elsewhere on the board
/P02: PLC1-2.11; also elsewhere on the board
/P03: JP11.1 (A), PLC1-2.10; also elsewhere on the board
/P04: PLC1-2.9; also elsewhere on the board
/P05: JP10.1 (A), PLC1-2.8; also elsewhere on the board
/P06: PLC1-2.7; also elsewhere on the board
/P07: JP9.1 (A), PLC1-2.6; also elsewhere on the board
/P08: PLC1-2.5; also elsewhere on the board
/P09: JP8.1 (A), PLC1-2.4; also elsewhere on the board
/P10: PLC1-2.3; also elsewhere on the board
/P11: JP7.1 (A), PLC1-2.2; also elsewhere on the board
/P12: PLC1-2.1; also elsewhere on the board
/P13: JP6.1 (A), PLC13-2.12; also elsewhere on the board
/P14: PLC13-2.11; also elsewhere on the board
/P15: JP5.1 (A), PLC13-2.10; also elsewhere on the board
/P16: PLC13-2.9; also elsewhere on the board
/P17: JP4.1 (A), PLC13-2.8; also elsewhere on the board
/P18: PLC13-2.7; also elsewhere on the board
/P19: JP3.1 (A), PLC13-2.6; also elsewhere on the board
/P20: PLC13-2.5; also elsewhere on the board
/P21: JP2.1 (A), PLC13-2.4; also elsewhere on the board
/P22: PLC13-2.3; also elsewhere on the board
/P23: JP1.1 (A), PLC13-2.2; also elsewhere on the board
/P24: PLC13-2.1; also elsewhere on the board
GND: JP1.2 (B), JP2.2 (B), JP3.2 (B), JP4.2 (B), JP5.2 (B), JP6.2 (B), JP7.2 (B), JP8.2 (B), JP9.2 (B), JP10.2 (B), JP11.2 (B), JP12.2 (B); also elsewhere on the board

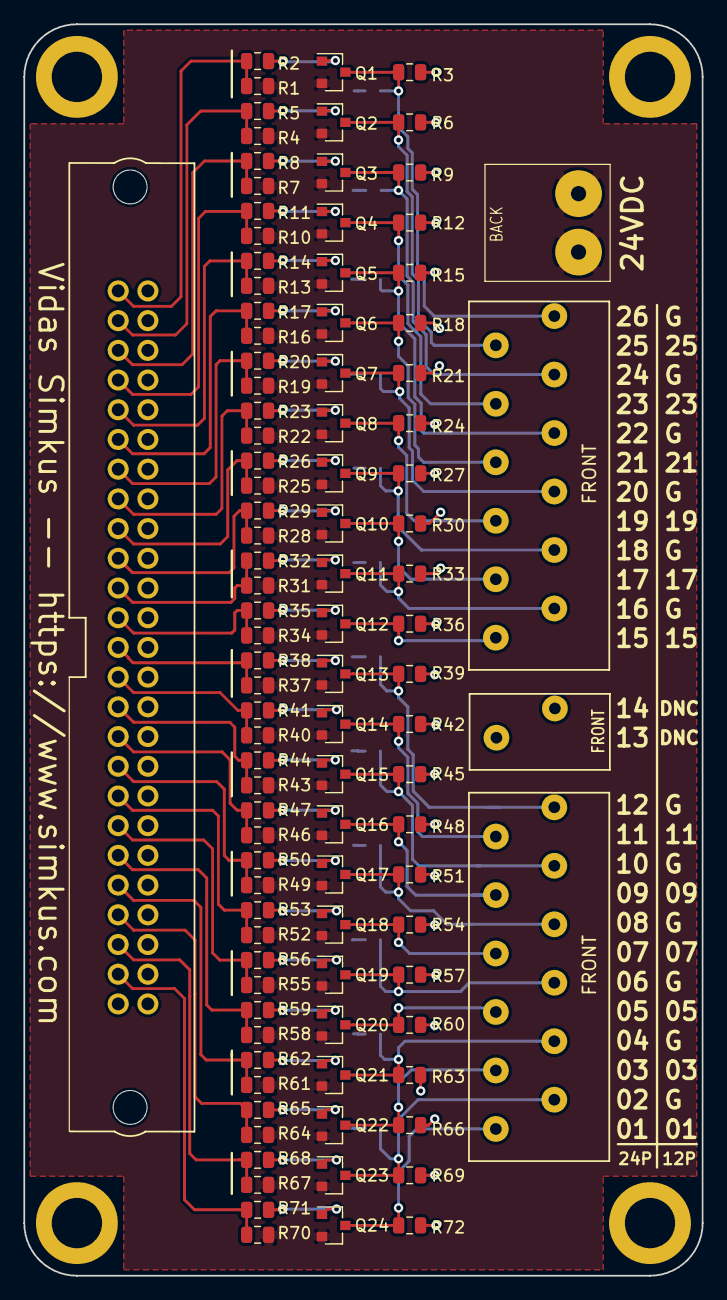
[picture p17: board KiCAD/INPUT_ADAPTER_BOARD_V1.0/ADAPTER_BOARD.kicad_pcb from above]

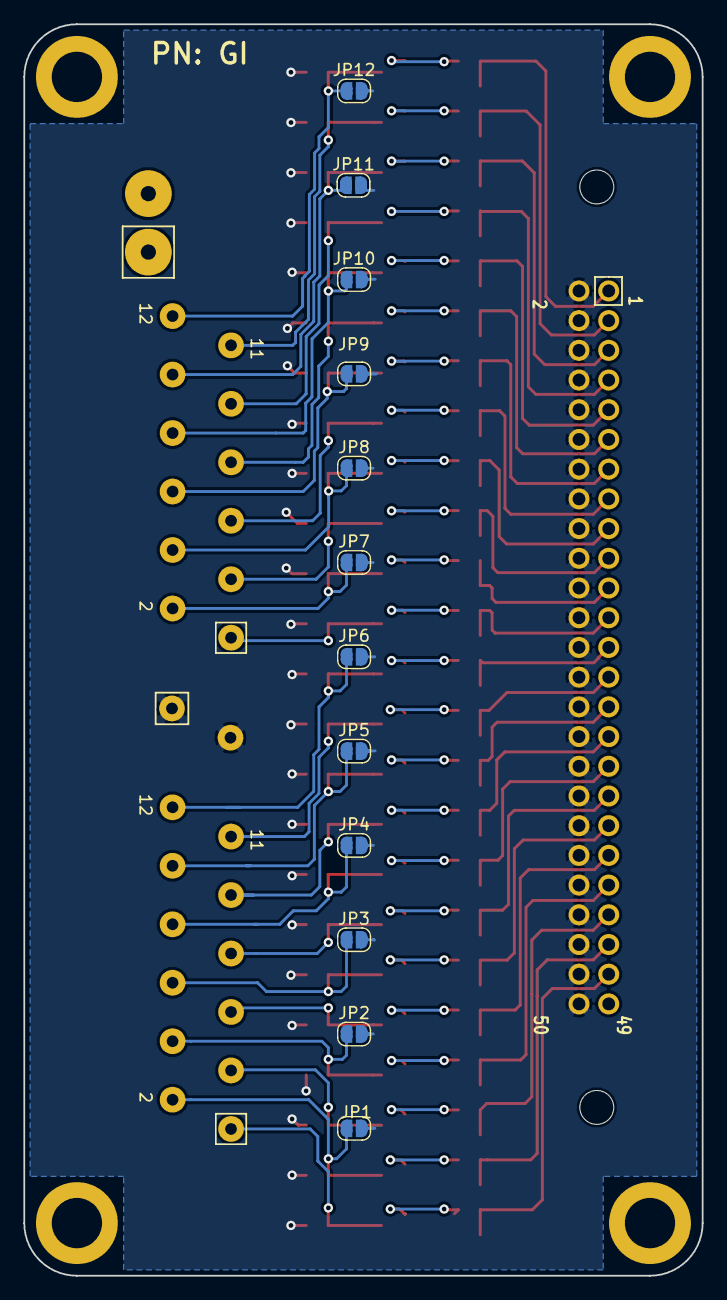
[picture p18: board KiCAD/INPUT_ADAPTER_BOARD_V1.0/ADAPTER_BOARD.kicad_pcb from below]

Board: 2 copper layers, 58.0 x 107.0 mm, 113 parts (12 on the bottom side), 74 nets.

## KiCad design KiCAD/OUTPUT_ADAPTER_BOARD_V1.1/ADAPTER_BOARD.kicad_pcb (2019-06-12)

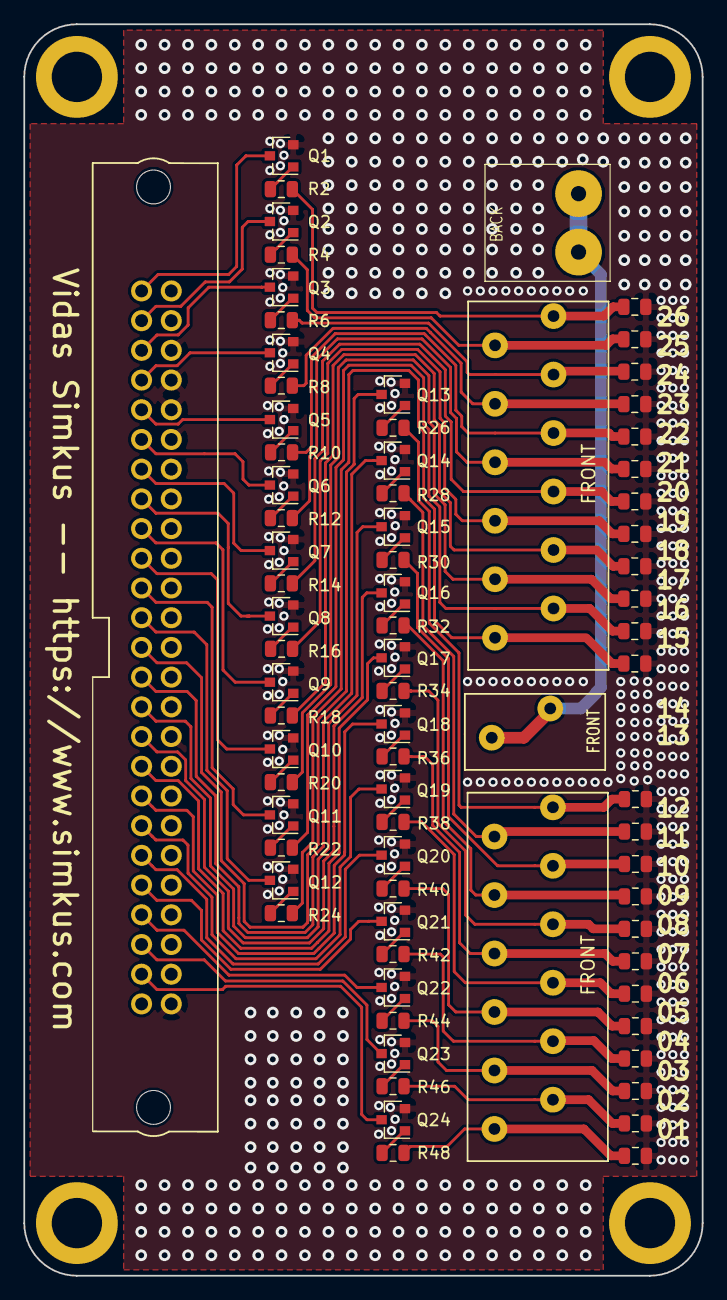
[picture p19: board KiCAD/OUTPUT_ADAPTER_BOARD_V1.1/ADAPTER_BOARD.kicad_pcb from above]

Board: 2 copper layers, 58.0 x 107.0 mm, 77 parts (0 on the bottom side), 74 nets.

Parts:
BOARD1: Conn_02x25_Odd_Even; FCI_50PIN
PLC1-12, PLC13-14: Conn_01x12; 12_POS_SPRING_TERM
PLC24: Conn_01x02; 2_POS_SPRING_TERM
Q1, Q2, Q3, Q4, Q5, Q6, Q7, Q8, Q9, Q10, Q11, Q12, Q13, Q14, Q15, Q16, Q17, Q18, Q19, Q20, Q21, Q22, Q23, Q24: Q_NPN_CBE; SOT-23
R1, R3, R5, R7, R9, R11, R13, R15, R17, R19, R21, R23, R25, R27, R29, R31, R33, R35, R37, R39, R41, R43, R45, R47: 10K; R_0805_2012Metric
R2, R4, R6, R8, R10, R12, R14, R16, R18, R20, R22, R24, R26, R28, R30, R32, R34, R36, R38, R40, R42, R44, R46, R48: 2K2; R_0805_2012Metric
VDC24: Conn_01x02; 2_POS_SCREW_TERM

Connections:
/24V: PLC24.1, PLC24.2, VDC24.1, VDC24.2
/B01: BOARD1.1, Q1.3
/B02: BOARD1.3, Q2.3
/B03: BOARD1.5, Q3.3
/B04: BOARD1.7, Q4.3
/B05: BOARD1.9, Q5.3
/B06: BOARD1.11, Q6.3
/B07: BOARD1.13, Q7.3
/B08: BOARD1.15, Q8.3
/B09: BOARD1.17, Q9.3
/B10: BOARD1.19, Q10.3
/B11: BOARD1.21, Q11.3
/B12: BOARD1.23, Q12.3
/B13: BOARD1.25, Q13.3
/B14: BOARD1.27, Q14.3
/B15: BOARD1.29, Q15.3
/B16: BOARD1.31, Q16.3
/B17: BOARD1.33, Q17.3
/B18: BOARD1.35, Q18.3
/B19: BOARD1.37, Q19.3
/B20: BOARD1.39, Q20.3
/B21: BOARD1.41, Q21.3
/B22: BOARD1.43, Q22.3
/B23: BOARD1.45, Q23.3
/B24: BOARD1.47, Q24.3
/P01: PLC1-12.12, R1.1, R2.2
/P02: PLC1-12.11, R3.1, R4.2
/P03: PLC1-12.10, R5.1, R6.2
/P04: PLC1-12.9, R7.1, R8.2
/P05: PLC1-12.8, R9.1, R10.2
/P06: PLC1-12.7, R11.1, R12.2
/P07: PLC1-12.6, R13.1, R14.2
/P08: PLC1-12.5, R15.1, R16.2
/P09: PLC1-12.4, R17.1, R18.2
/P10: PLC1-12.3, R19.1, R20.2
/P11: PLC1-12.2, R21.1, R22.2
/P12: PLC1-12.1, R23.1, R24.2
/P13: PLC13-14.12, R25.1, R26.2
/P14: PLC13-14.11, R27.1, R28.2
/P15: PLC13-14.10, R29.1, R30.2
/P16: PLC13-14.9, R31.1, R32.2
/P17: PLC13-14.8, R33.1, R34.2
/P18: PLC13-14.7, R35.1, R36.2
/P19: PLC13-14.6, R37.1, R38.2
/P20: PLC13-14.5, R39.1, R40.2
/P21: PLC13-14.4, R41.1, R42.2
/P22: PLC13-14.3, R43.1, R44.2
/P23: PLC13-14.2, R45.1, R46.2
/P24: PLC13-14.1, R47.1, R48.2
GND: BOARD1.2, BOARD1.4, BOARD1.6, BOARD1.8, BOARD1.10, BOARD1.12, BOARD1.14, BOARD1.16, BOARD1.18, BOARD1.20, BOARD1.22, BOARD1.24, BOARD1.26, BOARD1.28, BOARD1.30, BOARD1.32, BOARD1.34, BOARD1.36, BOARD1.38, BOARD1.40, BOARD1.42, BOARD1.44, BOARD1.46, BOARD1.48, BOARD1.50, Q1.2, Q2.2, Q3.2, Q4.2, Q5.2, Q6.2, Q7.2, Q8.2, Q9.2, Q10.2, Q11.2, Q12.2, Q13.2, Q14.2, Q15.2, Q16.2, Q17.2, Q18.2, Q19.2, Q20.2, Q21.2, Q22.2, Q23.2, Q24.2, R1.2, R3.2, R5.2, R7.2, R9.2, R11.2, R13.2, R15.2, R17.2, R19.2, R21.2, R23.2, R25.2, R27.2, R29.2, R31.2, R33.2, R35.2, R37.2, R39.2, R41.2, R43.2, R45.2, R47.2
unnamed: Q1.1, R2.1
unnamed: Q2.1, R4.1
unnamed: Q3.1, R6.1
unnamed: Q4.1, R8.1
unnamed: Q5.1, R10.1
unnamed: Q6.1, R12.1
unnamed: Q7.1, R14.1
unnamed: Q8.1, R16.1
unnamed: Q9.1, R18.1
unnamed: Q10.1, R20.1
unnamed: Q11.1, R22.1
unnamed: Q12.1, R24.1
unnamed: Q13.1, R26.1
unnamed: Q14.1, R28.1
unnamed: Q15.1, R30.1
unnamed: Q16.1, R32.1
unnamed: Q17.1, R34.1
unnamed: Q18.1, R36.1
unnamed: Q19.1, R38.1
unnamed: Q20.1, R40.1
unnamed: Q21.1, R42.1
unnamed: Q22.1, R44.1
unnamed: Q23.1, R46.1
unnamed: Q24.1, R48.1

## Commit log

2019-05-30 Initial import.
    [12POS_PCB_TERM_SPRING.dxf, 24POS_PCB_TERM.dxf, 2POS_PCB_TERM.dxf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]
2019-05-30 Added board screen shot
2019-05-30 Update README.md
    Added screen shot of board.
2019-06-11 Added DXF files.
    [ADAPTER_BOARD-drl_map.dxf, ADAPTER_BOARD.dxf]
2019-06-11 Moved around directory structure
    [ADAPTER_BOARD-B.Cu.gbl, ADAPTER_BOARD-B.Mask.gbs, ADAPTER_BOARD-B.Paste.gbp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]
2019-06-11 Text label updates.
    [ADAPTER_BOARD.kicad_pcb]
2019-06-12 V2 of the board.
2019-06-12 Created copy of output board V1.1 stuff as it was sent to fab.
    [ADAPTER_BOARD-B.Cu.gbl, ADAPTER_BOARD-B.Mask.gbs, ADAPTER_BOARD-B.Paste.gbp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]
2019-06-13 Started working on the input adapter.
    [ADAPTER_BOARD.kicad_pcb, ADAPTER_BOARD.sch, NPN_TRAN.sch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]
2019-06-19 Finalized and shipped the input adapter board V1.0 to production.
    [ADAPTER_BOARD-B.Cu.gbl, ADAPTER_BOARD-B.Mask.gbs, ADAPTER_BOARD-B.Paste.gbp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]
2019-06-19 Archived V1.0 that was sent to production.
    [ADAPTER_BOARD-B.Cu.gbl, ADAPTER_BOARD-B.Mask.gbs, ADAPTER_BOARD-B.Paste.gbp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]
2019-06-19 Footprint updates.
    [ADAPTER_BOARD-drl_map.dxf, ADAPTER_BOARD.dxf, ADAPTER_BOARD.kicad_pcb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]
2019-08-17 Updated BOM files.
    [ADAPTER_BOARD_bom_V1.0.csv, ADAPTER_BOARD_bom_V1.0.ods]
2019-08-17 Added PDF export of BOM file.
    [ADAPTER_BOARD_bom_V1.0.ods]
